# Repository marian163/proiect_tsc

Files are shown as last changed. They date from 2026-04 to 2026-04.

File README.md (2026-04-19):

# InkTime v6 — documentație hardware

## 1. Funcționalitatea hardware

InkTime v6 este un dispozitiv portabil cu ecran e-paper, construit în jurul microcontroller-ului **Nordic nRF52840** (Cortex-M4F @ 64 MHz, 1 MB Flash, 256 KB RAM, BLE 5, USB 2.0 full-speed, NFC-A). Cristalul principal de **32 MHz** (X1) alimentează CPU-ul și radio-ul, iar cristalul de **32.768 kHz** (X2) este folosit pentru RTC-ul low-power. Antena este un chip **2450AT18B100E** conectat la pinul ANT prin rețea de match în π (15 nH, 10 µH, 1 pF, 820 pF).

**Domeniul de alimentare.** Tensiunea intră prin conectorul **USB-C KH-TYPE-C-16P** (5 V VBUS), cu rezistențe CC de 5.1 kΩ care configurează placa ca UFP 500 mA și cu protecție ESD **USBLC6-2SC6Y** pe liniile D+/D−. VBUS ajunge la încărcătorul Li-Po **TI BQ25180** (I²C, adresă 0x6A), care gestionează o baterie Li-Po conectată prin **Molex 503480**. Ieșirea SYS a încărcătorului alimentează convertorul buck-boost **Richtek RT6160AWSC** (inductanța 0.47 µH + 10 µF/22 µF, feedback 3.3 kΩ) care produce șina stabilă **VREG = 3.3 V** indiferent de nivelul bateriei (3.0–4.2 V). Un **MAX17048** (I²C, 0x36) măsoară starea de încărcare prin ModelGauge fără shunt și generează ALERT la baterie scăzută.

**Periferice I²C.** Toate perifericele non-display partajează aceeași magistrală I²C cu nRF52840:

- **BMA421** (0x18) — accelerometru 3 axe Bosch, low-power (~14 µA @ 50 Hz), cu două linii de întrerupere (INT1, INT2) pentru detecție mișcare/tap/pas.
- **MAX17048** (0x36) — fuel gauge, cu pin ALERT open-drain.
- **DRV2605** (0x5A) — driver haptic cu bibliotecă internă de 123 efecte, cu pin EN dedicat pentru shutdown complet (~0.1 µA).
- **BQ25180** (0x6A) — încărcător, cu pin INT (PMIC_INT) pentru status de încărcare.

**Ecranul e-paper.** Conectorul FPC cu 24 de pini (J1) expune interfața SPI (MOSI, SCK, CS) plus semnale de control (DC, RST, BUSY) și alimentarea EPD_3V3. Tensiunile înalte necesare panelului (VGH ~+22 V, VGL ~−20 V) sunt generate local printr-un boost converter cu **inductanță 68 µH** + MOSFET N **SI1308** + diode Schottky **MBR0530** + condensatoare 1 µF / 50 V. Alimentarea logică a panelului este comutată de un PMOS **DMG2305UX-7**, permițând oprirea completă a ecranului între refresh-uri.

**Butoane și debug.** Trei butoane (SW_UP, SW_DN, SW_ENT) citite pe GPIO cu pull-up 10 kΩ. Header **TC2030-IDC** pentru SWD (SWDIO, SWDCLK, SWO, RESET).

**Consum estimat.** În sleep total ~30 µA (nRF52840 System OFF 1.5 µA + IMU low-power 4 µA + fuel gauge 23 µA + charger 1.5 µA, ecran complet off). Per refresh e-paper: ~25 mA timp de ~2 s. Cu o baterie de 150 mAh și 4 refresh-uri/zi + BLE advertising la 1 Hz, autonomia estimată este de ~100–130 zile.

---

## 2. Maparea pinilor nRF52840

Principii de alegere:

- pinii oscilatorilor (XL1/XL2, XC1/XC2), radio (ANT), USB (D+/D−) și NFC (NFC1/NFC2) sunt **fixați de chip** și nu pot fi folosiți altfel;
- liniile de întrerupere (INT1/INT2, ALERT, PMIC_INT, butoane) sunt plasate pe pini care permit wake-up din System OFF;
- magistralele seriale (I²C, SPI) sunt routabile liber pe orice GPIO — alegerile reflectă routing-ul fizic cel mai scurt pe PCB.

| Pin nRF52840 | Semnal | Funcție | Motiv alegere |
|---|---|---|---|
| P0.00 / XL1 | XL1 | Cristal 32.768 kHz | Pin dedicat oscilator LF |
| P0.01 / XL2 | XL2 | Cristal 32.768 kHz | Pin dedicat oscilator LF |
| XC1 / XC2 | HFCLK | Cristal 32 MHz | Pini dedicați oscilator HF |
| ANT | RF | Antenă 2.4 GHz | Pin dedicat radio |
| D+ / D− | USB data | USB-C (prin USBLC6) | Pini dedicați USB |
| VBUS | 5 V sense  | Detecție USB conectat | Pin dedicat USB |
| P0.04 | SDA | I²C data (shared) | GPIO central, routing scurt la toate perifericele |
| P1.09 | SCL | I²C clock (shared) | GPIO adiacent SDA |
| P0.13 | MOSI | SPI MOSI → e-paper | GPIO apropiat fizic de conector FPC |
| P0.14 | SCK | SPI clock → e-paper | GPIO adiacent MOSI |
| P0.26 | EPD_CS | SPI chip-select e-paper | GPIO simplu, aproape de FPC |
| P0.27 | EPD_DC | Data/Command e-paper | GPIO simplu, aproape de FPC |
| P1.01 | EPD_RST | Reset e-paper | GPIO (poate fi ținut low în sleep) |
| P1.02 | EPD_BUSY | Busy signal de la panel | GPIO intrare cu detecție de front |
| P1.03 | HAPTIC_EN  | Enable DRV2605 | GPIO simplu, low = shutdown |
| P1.04 | EPD_3V3_EN | Gate PMOS alimentare e-paper | GPIO simplu, controlează alimentarea panelului |
| P1.05 | IMU_INT1 | Întrerupere IMU (motion/activity) | Pin cu wake-up din System OFF |
| P1.06 | IMU_INT2 | Întrerupere IMU (tap/step) | Pin cu wake-up din System OFF |
| P1.07 | ALERT | Întrerupere fuel gauge | Pin cu wake-up (low-battery) |
| P1.08 | PMIC_INT | Întrerupere BQ25180 (charge status) | Pin cu wake-up |
| P0.22 | SW_UP | Buton sus | GPIO cu pull-up + wake-up |
| P0.23 | SW_DN | Buton jos | GPIO cu pull-up + wake-up |
| P0.24 | SW_ENT | Buton enter | GPIO cu pull-up + wake-up |
| SWDCLK | SWDCLK | Debug clock | Pin dedicat debug |
| SWDIO | SWDIO | Debug data | Pin dedicat debug |
| P0.18 / RESET | RESET | Reset hardware | Pin dedicat reset |
| P1.00 / SWO | SWO | Trace output (opțional) | Pin SWO dedicat |

---

## 3. Decizii de implementare

Ideal, schematicul ar fi trebuit împărțit pe două sheet-uri (MCU + alimentare separat de ecran + periferice), așa cum este modelul de referință. În practică, am desenat tot pe un singur sheet de la început și, până când mi-am dat seama că două ar fi fost mai lizibil, PCB-ul era deja rutat — orice restructurare a schematicului ar fi invalidat rutarea existentă. Am păstrat single-sheet-ul ca atare; este mai dens și mai greu de citit, dar funcțional.

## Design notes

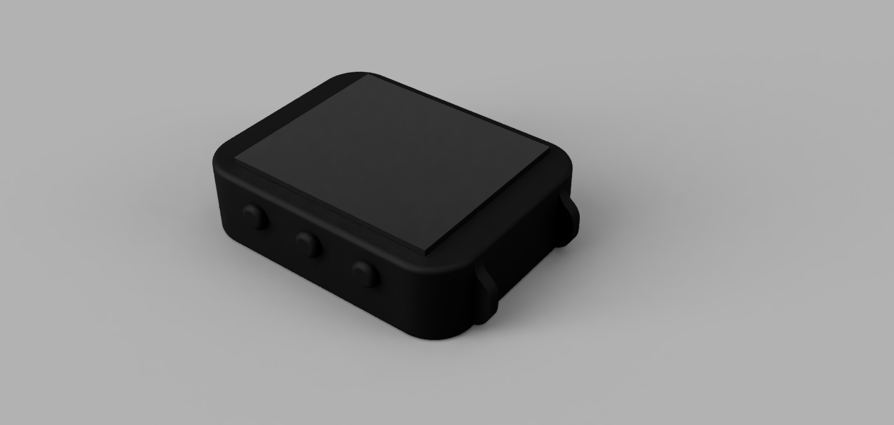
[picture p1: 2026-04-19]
Images/3d_Design_render.PNG

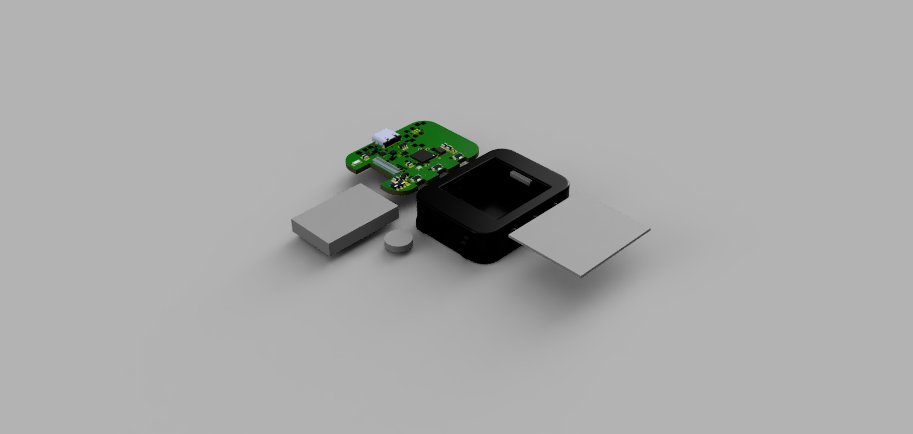
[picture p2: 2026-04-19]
Images/3D_Design_exploded_render.png

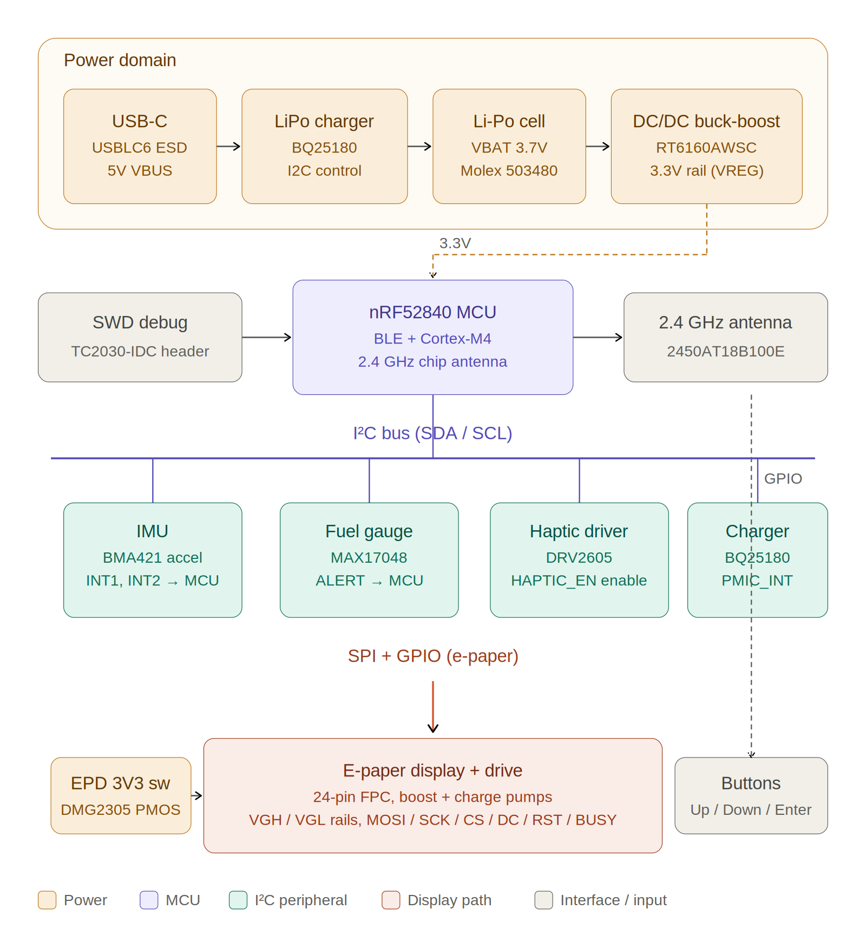
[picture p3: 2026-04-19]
Images/inktime_block_diagram.png

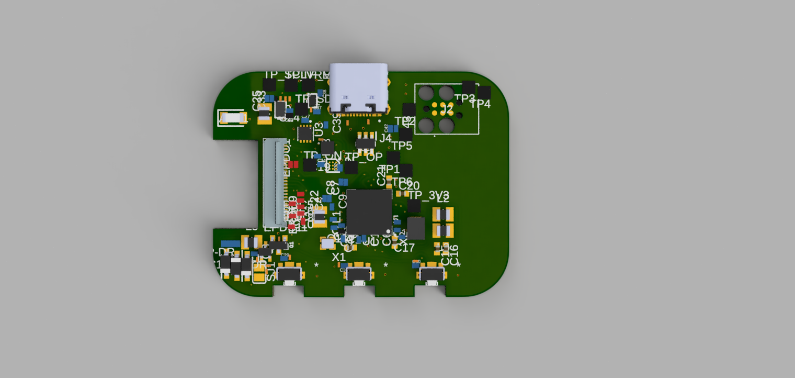
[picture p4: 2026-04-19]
Images/3D_PCB_render.PNG

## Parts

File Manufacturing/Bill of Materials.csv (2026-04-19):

Qty | Value | Device | Package | Parts | Description | ARROW_PART_NUMBER | ARROW_PRICE-STOCK | AVAILABILITY | CATEGORY | CHECK_PRICES | COPYRIGHT | DATASHEET | DESCRIPTION | DIGI-KEY_PART_NUMBER_1 | DIGI-KEY_PART_NUMBER_2 | DIGI-KEY_PART_NUMBER_3 | FREQUENCY | GPIO | HEIGHT | JLCPCB | L2 | L3 | MANUFACTURER | MANUFACTURER_NAME | MANUFACTURER_PART_NUMBER | MF | MOUSER_PART_NUMBER | MOUSER_PRICE-STOCK | MP | MPN | OPERATING_TEMPERATURE | PACKAGE | PACKAGE_SIZE | PACKAGE_TYPE | PART_STATUS | POPULARITY | PRICE | PROD_ID | PURCHASE-URL | R2 | R4 | R9 | ROHS | SERIES | SNAPEDA_LINK | SPICEMODEL | SPICEPREFIX | SUBCATEGORY | THERMALLOSS | TP_SIGNAL_NAME | TYPE | VALUE
1 | 0 | ERA-1AEB3401C_CPF0201D7K68C1 | ERA-1AEB3401C_0201 | R2 | 7.68k 0201 Thin Film Surface Mount Fixed Resistor +/-0.5% 0.031W CPF0201D7K68C1 |  |  |  |  |  |  |  |  |  |  |  |  |  |  |  |  |  |  |  |  |  |  |  |  |  |  |  |  |  |  |  |  |  |  |  | 0
2 | 0 | ERA-1AEB3401C_CPF0201D7K68C1 | ERA-1AEB3401C_0201 | R3, R4 | 7.68k 0201 Thin Film Surface Mount Fixed Resistor +/-0.5% 0.031W CPF0201D7K68C1 |  |  |  |  |  |  |  |  |  |  |  |  |  |  |  |  |  |  |  |  |  |  |  |  |  |  |  |  |  |  |  |  |  |  | 0
1 | 0 | ESP32_C6_LIBRARY_7_JUMPER_SJ | ESP32_C6_LIBRARY_7_JUMPER_SJ | SJ1 | SMD solder JUMPER |  |  |  |  |  |  |  |  |  |  |  |  |  |  |  |  |  |  |  |  |  |  |  |  |  |  |  |  |  |  | 3
3 | 0.1uF | GRM011R60J152KE01L_2_GRM011R60J152KE01L | GRM011R60J152KE01L_2_CAPC0201X13N | C23, C27, C42 | Check availability |  |  | In Stock |  | https://www.snapeda.com/parts/GRM011R60J152KE01L/Murata/view-part/?ref=eda |  |  | SMD Capacitor X5R(EIA) with Capacitance: 1500pF Tol. 10%. Rated Voltage: 6.3Vdc |  |  |  |  |  |  |  |  |  |  |  |  | Murata |  |  | GRM011R60J152KE01L |  |  | 0201 Murata |  |  |  |  | None |  |  |  |  |  |  |  | https://www.snapeda.com/parts/GRM011R60J152KE01L/Murata/view-part/?ref=snap
1 | 0.47 | ERA-1AEB3401C_CPF0201D7K68C1 | ERA-1AEB3401C_0201 | R1_EP_DR | 7.68k 0201 Thin Film Surface Mount Fixed Resistor +/-0.5% 0.031W CPF0201D7K68C1
1 | 01.uF | GRM011R60J152KE01L_2_GRM011R60J152KE01L | GRM011R60J152KE01L_2_CAPC0201X13N | C34 | Check availability |  |  | In Stock |  | https://www.snapeda.com/parts/GRM011R60J152KE01L/Murata/view-part/?ref=eda |  |  | SMD Capacitor X5R(EIA) with Capacitance: 1500pF Tol. 10%. Rated Voltage: 6.3Vdc |  |  |  |  |  |  |  |  |  |  |  |  | Murata |  |  | GRM011R60J152KE01L |  |  | 0201 Murata |  |  |  |  | None |  |  |  |  |  |  |  | https://www.snapeda.com/parts/GRM011R60J152KE01L/Murata/view-part/?ref=snap
1 | 1.0µF | ESP32_C6_LIBRARY_1_ESP32_WROVER_EAGLE-LTSPICE_CC0402 | ESP32_C6_LIBRARY_1_ESP32_WROVER_EAGLE-LTSPICE_C0402 | C15 | CAPACITOR, European symbol |  |  |  |  |  |  |  |  |  |  |  |  |  |  |  |  |  |  |  |  |  |  |  |  |  |  |  |  |  |  |  |  |  |  |  |  |  |  |  |  | NONE | C
5 | 100nF | NORDIC_NRF_3_CAPACITOR_0201_L | NORDIC_NRF_3_RESC0201_L | C5, C7, C8, C12, C19 | Generic chip capacitor
1 | 100pF | NORDIC_NRF_3_CAPACITOR_0201_L | NORDIC_NRF_3_RESC0201_L | C11 | Generic chip capacitor
5 | 10K | ERA-1AEB3401C_CPF0201D7K68C1 | ERA-1AEB3401C_0201 | R2_EP_DR, R5, R7, R8, R_PWR_EPD | 7.68k 0201 Thin Film Surface Mount Fixed Resistor +/-0.5% 0.031W CPF0201D7K68C1
1 | 10K | ERA-1AEB3401C_CPF0201D7K68C1 | ERA-1AEB3401C_0201 | R9 | 7.68k 0201 Thin Film Surface Mount Fixed Resistor +/-0.5% 0.031W CPF0201D7K68C1 |  |  |  |  |  |  |  |  |  |  |  |  |  |  |  |  |  |  |  |  |  |  |  |  |  |  |  |  |  |  |  |  |  |  |  |  | 10K
1 | 10nF | NORDIC_NRF_3_CAPACITOR_0201_L | NORDIC_NRF_3_RESC0201_L | C39 | Generic chip capacitor
2 | 10uF | NORDIC_NRF_3_CAPACITOR_0201_L | NORDIC_NRF_3_RESC0201_L | C1_EP_DR, C24 | Generic chip capacitor
1 | 10µH | MLP2016SR47MT0S1_FTC252012SR47MBCA | MLP2016SR47MT0S1_INDC2016X100N | L2 | SMD / SMT Inductors (Coils), L=0.47?H, L x W x T : |  |  |  |  |  |  |  | SMD / SMT Inductors (Coils) | L=0.47?H | L x W x T : |  |  |  |  |  | 1mm | https://jlcpcb.com/partdetail/6763488-FTC252012SR47MBCA/C5832368 | 10µH |  |  | TDK | FTC252012SR47MBCA
3 | 12pF | NORDIC_NRF_3_CAPACITOR_0201_L | NORDIC_NRF_3_RESC0201_L | C1, C17, C18 | Generic chip capacitor
1 | 15nH | MLP2016SR47MT0S1_FTC252012SR47MBCA | MLP2016SR47MT0S1_INDC2016X100N | L3 | SMD / SMT Inductors (Coils), L=0.47?H, L x W x T : |  |  |  |  |  |  |  | SMD / SMT Inductors (Coils) | L=0.47?H | L x W x T : |  |  |  |  |  | 1mm | https://jlcpcb.com/partdetail/6763488-FTC252012SR47MBCA/C5832368 |  | 15nH |  | TDK | FTC252012SR47MBCA
2 | 1pF | NORDIC_NRF_3_CAPACITOR_0201_L | NORDIC_NRF_3_RESC0201_L | C3, C4 | Generic chip capacitor
6 | 1uF | GRM011R60J152KE01L_2_GRM011R60J152KE01L | GRM011R60J152KE01L_2_CAPC0201X13N | C29, C30, C31, C32, C37, C38 | Check availability |  |  | In Stock |  | https://www.snapeda.com/parts/GRM011R60J152KE01L/Murata/view-part/?ref=eda |  |  | SMD Capacitor X5R(EIA) with Capacitance: 1500pF Tol. 10%. Rated Voltage: 6.3Vdc |  |  |  |  |  |  |  |  |  |  |  |  | Murata |  |  | GRM011R60J152KE01L |  |  | 0201 Murata |  |  |  |  | None |  |  |  |  |  |  |  | https://www.snapeda.com/parts/GRM011R60J152KE01L/Murata/view-part/?ref=snap
10 | 1uF/50V | NORDIC_NRF_3_CAPACITOR_0201_L | NORDIC_NRF_3_RESC0201_L | EPDC1, EPDC2, EPDC5, EPDC6, EPDC7, EPDC8, EPDC9, EPDC10, EPDC11, EPDC12 | Generic chip capacitor
1 | 2.2 | ERA-1AEB3401C_CPF0201D7K68C1 | ERA-1AEB3401C_0201 | R_TYPE_SEL | 7.68k 0201 Thin Film Surface Mount Fixed Resistor +/-0.5% 0.031W CPF0201D7K68C1
3 | 2025-10-22_07-23-44_LIBRARY_EVP-AKE31ASW_EVP-AKE31A_PAN | 2025-10-22_07-23-44_LIBRARY_EVP-AKE31ASW_EVP-AKE31A_PAN | 2025-10-22_07-23-44_LIBRARY_SW_EVP-AKE31A_PAN | SW_DN, SW_ENT, SW_UP |  |  |  |  |  |  | Copyright (C) 2025 Ultra Librarian. All rights reserved. |  |  | P123437TR-ND | P123437CT-ND | P123437DKR-ND |  |  |  |  |  |  |  | Panasonic | EVP-AKE31A
1 | 20V/4.2A/52mO/1.4W | ESP32_C6_LIBRARY_4_ESP32_WROVER_SPARKFUN-DISCRETESEMI_MOSFET_PCH-DMG2305UX-7 | ESP32_C6_LIBRARY_4_ESP32_C6_LIBRARY_4_ESP32_C6_LIBRARY_4_ESP32_C6_LIBRARY_4_ESP32_WROVER_SPARKFUN-DISCRETESEMI_SOT23-3 | Q1 | P-channel MOSFETs |  |  |  |  |  |  |  |  |  |  |  |  |  |  |  |  |  |  |  |  |  |  |  |  |  |  |  |  |  |  |  |  | TRAN-14388 |  |  |  |  |  |  |  |  |  |  |  |  |  | 20V/4.2A/52mO/1.4W
2 | 22nF | NORDIC_NRF_3_CAPACITOR_0201_L | NORDIC_NRF_3_RESC0201_L | C25, C33 | Generic chip capacitor
1 | 2450AT18B100E_2450AT18B100E | 2450AT18B100E_2450AT18B100E | 2450AT18B100E_ANTC3216X140N | ANT1 | Antennas 2.45GHz ANTENNA | 2450AT18B100E | https://www.arrow.com/en/products/2450at18b100e/johanson-dielectrics?utm_currency=USD&region=nac |  |  |  |  |  | Antennas 2.45GHz ANTENNA |  |  |  |  |  | 1.4mm |  |  |  |  | JOHANSON TECHNOLOGY | 2450AT18B100E |  | 609-2450AT18B100E | https://www.mouser.co.uk/ProductDetail/Johanson-Technology/2450AT18B100E?qs=yCnrNFeXz%252Bh5MFsFIXGZGA%3D%3D
1 | 32.768kH | NORDIC_NRF_1_XTAL_32KHZ | NORDIC_NRF_1_XTAL_3215_N | X2
1 | 32MHz | NORDIC_NRF_XTAL_32MHZ | NORDIC_NRF_BT-XTAL_2016_N | X1
1 | 4.7nF | NORDIC_NRF_3_CAPACITOR_0201_L | NORDIC_NRF_3_RESC0201_L | C43 | Generic chip capacitor
1 | 4.7uF | ESP32_C6_LIBRARY_1_ESP32_WROVER_EAGLE-LTSPICE_CC0402 | ESP32_C6_LIBRARY_1_ESP32_WROVER_EAGLE-LTSPICE_C0402 | C2-EP-DR | CAPACITOR, European symbol |  |  |  |  |  |  |  |  |  |  |  |  |  |  |  |  |  |  |  |  |  |  |  |  |  |  |  |  |  |  |  |  |  |  |  |  |  |  |  |  | NONE | C
4 | 4.7µF | ESP32_C6_LIBRARY_1_ESP32_WROVER_EAGLE-LTSPICE_CC0402 | ESP32_C6_LIBRARY_1_ESP32_WROVER_EAGLE-LTSPICE_C0402 | C6, C14, C20, C21 | CAPACITOR, European symbol |  |  |  |  |  |  |  |  |  |  |  |  |  |  |  |  |  |  |  |  |  |  |  |  |  |  |  |  |  |  |  |  |  |  |  |  |  |  |  |  | NONE | C
1 | 47nF | ESP32_C6_LIBRARY_1_ESP32_WROVER_EAGLE-LTSPICE_CC0402 | ESP32_C6_LIBRARY_1_ESP32_WROVER_EAGLE-LTSPICE_C0402 | C16 | CAPACITOR, European symbol |  |  |  |  |  |  |  |  |  |  |  |  |  |  |  |  |  |  |  |  |  |  |  |  |  |  |  |  |  |  |  |  |  |  |  |  |  |  |  |  | NONE | C
1 | 503480-2400_503480-2400 | 503480-2400_503480-2400 | 503480-2400_5034802400 | J1 | FFC & FPC Connectors 0.5mm FPC RA SMT Dual Contact 24Ckt |  |  |  |  |  |  |  | FFC & FPC Connectors 0.5mm FPC RA SMT Dual Contact 24Ckt |  |  |  |  |  | 1.87mm |  |  |  |  | Molex | 503480-2400 |  | 538-503480-2400 | https://www.mouser.co.uk/ProductDetail/Molex/503480-2400?qs=OAhjpuo3Vu7efIoxFh9AOw%3D%3D
2 | 5K1 | ERA-1AEB3401C_CPF0201D7K68C1 | ERA-1AEB3401C_0201 | R1_USB, R2_USB | 7.68k 0201 Thin Film Surface Mount Fixed Resistor +/-0.5% 0.031W CPF0201D7K68C1
1 | 68uH | MLP2016SR47MT0S1_FTC252012SR47MBCA | MLP2016SR47MT0S1_INDC2016X100N | L5 | SMD / SMT Inductors (Coils), L=0.47?H, L x W x T : |  |  |  |  |  |  |  | SMD / SMT Inductors (Coils) | L=0.47?H | L x W x T : |  |  |  |  |  | 1mm | https://jlcpcb.com/partdetail/6763488-FTC252012SR47MBCA/C5832368 |  |  |  | TDK | FTC252012SR47MBCA
1 | 820pF | NORDIC_NRF_3_CAPACITOR_0201_L | NORDIC_NRF_3_RESC0201_L | C9 | Generic chip capacitor
1 | BMA423_BMA423 | BMA423_BMA423 | BMA423_BMA423 | IC3 | Accelerometers Triaxial low-g 12bit Acceleration Sensor | BMA423 | https://www.arrow.com/en/products/bma423/bosch |  |  |  |  |  | Accelerometers Triaxial low-g 12bit Acceleration Sensor |  |  |  |  |  | 1mm |  |  |  |  | BOSCH | BMA423 |  | 262-BMA423 | https://www.mouser.co.uk/ProductDetail/Bosch-Sensortec/BMA423?qs=HXFqYaX1Q2xC%252BSgeGoX3mg%3D%3D
1 | BQ25180YBGR_BQ25180YBGR | BQ25180YBGR_BQ25180YBGR | BQ25180YBGR_BGA8C40P2X4_100X155X50 | IC1 | Charger IC Lithium Ion/Polymer, Lithium Iron Phosphate 8-DSBGA (1.6x1.1) | BQ25180YBGR | https://www.arrow.com/en/products/bq25180ybgr/texas-instruments?utm_currency=USD&region=nac |  |  |  |  |  | Charger IC Lithium Ion/Polymer | Lithium Iron Phosphate 8-DSBGA (1.6x1.1) |  |  |  |  |  | 0.5mm |  |  |  |  | Texas Instruments | BQ25180YBGR |  | 595-BQ25180YBGR | https://www.mouser.co.uk/ProductDetail/Texas-Instruments/BQ25180YBGR?qs=doiCPypUmgEWjAK%252BJAX6Tw%3D%3D
1 | DRV2605YZFR_DRV2605YZFR | DRV2605YZFR_DRV2605YZFR | DRV2605YZFR_BGA9C50P3X3_144X144X62 | IC2 | Haptic Driver for ERM/LRA with Built-In Library and Smart Loop Architecture | DRV2605YZFR | https://www.arrow.com/en/products/drv2605yzfr/texas-instruments?region=nac |  |  |  |  |  | Haptic Driver for ERM/LRA with Built-In Library and Smart Loop Architecture |  |  |  |  |  | 0.625mm |  |  |  |  | Texas Instruments | DRV2605YZFR
2 | ERA-1AEB3401C_CPF0201D7K68C1 | ERA-1AEB3401C_CPF0201D7K68C1 | ERA-1AEB3401C_0201 | R17, R18 | 7.68k 0201 Thin Film Surface Mount Fixed Resistor +/-0.5% 0.031W CPF0201D7K68C1
1 | ESP32_C6_LIBRARY_3_USBLC6-2SC6Y | ESP32_C6_LIBRARY_3_USBLC6-2SC6Y | ESP32_C6_LIBRARY_3_SOT95P280X145-6N | D3 | Low Cap. ESD Protection Auto SOT-23-6 STMicroelectronics USBLC6-2SC6Y, Dual Uni-Directional TVS Diode Array, 6-Pin SOT-23 |  |  | In Stock |  | https://www.snapeda.com/parts/USBLC6-2SC6Y/STMicroelectronics/view-part/?ref=eda |  |  | 17V Clamp 5A (8/20µs) Ipp Tvs Diode Surface Mount SOT-23-6 |  |  |  |  |  |  |  |  |  |  |  |  | STMicroelectronics |  |  | USBLC6-2SC6Y |  |  | SOT-23-6 STMicroelectronics |  |  |  |  | None |  |  |  |  |  |  |  | https://www.snapeda.com/parts/USBLC6-2SC6Y/STMicroelectronics/view-part/?ref=snap
3 | ESP32_C6_LIBRARY_5_MBR0530 | ESP32_C6_LIBRARY_5_MBR0530 | ESP32_C6_LIBRARY_5_SOD3716X135N | D2, D4, D5 | ON SEMICONDUCTOR - MBR0530 - DIODE, SCHOTTKY, 0.5A, 30V, SOD-123 |  |  | In Stock |  | https://www.snapeda.com/parts/MBR0530/Onsemi/view-part/?ref=eda |  |  | Diode Schottky 30 V 500mA Surface Mount SOD-123 |  |  |  |  |  |  |  |  |  |  |  |  | ON Semiconductor |  |  | MBR0530 |  |  | SOD-123-2 ON Semiconductor |  |  |  |  | None |  | https://www.snapeda.com/api/url_track_click_mouser/?unipart_id=179458&manufacturer=ON Semiconductor&part_name=MBR0530&search_term=None |  |  |  |  |  | https://www.snapeda.com/parts/MBR0530/Onsemi/view-part/?ref=snap
1 | ESP32_C6_LIBRARY_6_SI1308EDL-T1-GE3 | ESP32_C6_LIBRARY_6_SI1308EDL-T1-GE3 | ESP32_C6_LIBRARY_6_SOT65P210X110-3N | Q3 | MOSFET N-Ch 30V 1.5A TrenchFET SC70 Vishay Si1308EDL-T1-GE3 N-channel MOSFET Transistor, 1.5 A, 30 V, 3-Pin SC-70 |  |  | In Stock |  | https://www.snapeda.com/parts/SI1308EDL-T1-GE3/Vishay+Siliconix/view-part/?ref=eda |  |  | Si1308EDL-T1-GE3 N-channel MOSFET Transistor | 1.5 A | 30 V | 3-Pin SC-70 | Siliconix / Vishay SI1308EDL-T1-GE3 |  |  |  |  |  |  |  |  |  |  |  |  | Vishay Siliconix |  |  | SI1308EDL-T1-GE3 |  |  | SOT-323 Vishay Semiconductor |  |  |  |  | None |  | https://www.snapeda.com/api/url_track_click_mouser/?unipart_id=274603&manufacturer=Vishay Siliconix&part_name=SI1308EDL-T1-GE3&search_term=None |  |  |  |  |  | https://www.snapeda.com/parts/SI1308EDL-T1-GE3/Vishay+Siliconix/view-part/?ref=snap
1 | ESP32_C6_LIBRARY_MAX17048G+T10 | ESP32_C6_LIBRARY_MAX17048G+T10 | ESP32_C6_LIBRARY_SON50P200X200X80-9N | U3 | Check availability |  |  | In Stock |  | https://www.snapeda.com/parts/MAX17048G+T10/Analog+Devices/view-part/?ref=eda |  |  | 3µA 1-Cell/2-Cell Fuel Gauge with ModelGauge |  |  |  |  |  |  |  |  |  |  |  |  | Analog Devices |  |  | MAX17048G+T10 |  |  | TDFN-8 Maxim |  |  |  |  | None |  | https://www.snapeda.com/api/url_track_click_mouser/?unipart_id=329239&manufacturer=Analog Devices&part_name=MAX17048G+T10&search_term=None |  |  |  |  |  | https://www.snapeda.com/parts/MAX17048G+T10/Analog+Devices/view-part/?ref=snap
13 | HECTOR_WATCH_1_TPTP20R | HECTOR_WATCH_1_TPTP20R | HECTOR_WATCH_1_TP20R | TP1, TP2, TP3, TP4, TP5, TP6, TP_3V3, TP_ON, TP_OP, TP_SCL, TP_SDA, TP_VBAT, TP_VREG | Test pad |  |  |  |  |  |  |  |  |  |  |  |  |  |  |  |  |  |  |  |  |  |  |  |  |  |  |  |  |  |  | 2
1 | KH-TYPE-C-16P_KH-TYPE-C-16P | KH-TYPE-C-16P_KH-TYPE-C-16P | KH-TYPE-C-16P_KINGHELM_KH-TYPE-C-16P | J4 | Check availability |  |  | Not in stock |  | https://www.snapeda.com/parts/KH-TYPE-C-16P/Kinghelm/view-part/?ref=eda |  |  |  |  |  |  |  |  |  |  |  |  |  |  |  | kinghelm |  |  | KH-TYPE-C-16P |  |  | None |  |  |  |  | None |  |  |  |  |  |  |  | https://www.snapeda.com/parts/KH-TYPE-C-16P/Kinghelm/view-part/?ref=snap
2 | MLP2016SR47MT0S1_FTC252012SR47MBCA | MLP2016SR47MT0S1_FTC252012SR47MBCA | MLP2016SR47MT0S1_INDC2016X100N | L1, L7 | SMD / SMT Inductors (Coils), L=0.47?H, L x W x T : |  |  |  |  |  |  |  | SMD / SMT Inductors (Coils) | L=0.47?H | L x W x T : |  |  |  |  |  | 1mm | https://jlcpcb.com/partdetail/6763488-FTC252012SR47MBCA/C5832368 |  |  |  | TDK | FTC252012SR47MBCA
4 | N.C. | NORDIC_NRF_3_CAPACITOR_0201_L | NORDIC_NRF_3_RESC0201_L | C2, C10, C13, C22 | Generic chip capacitor
1 | NRF52840-QIAA-R | NRF52840-QIAA-R | NRF52840-QIAA | U1 | Bluetooth®5 IEEE 802.15.4-2006 2.4 GHz transceiver - SoC |  |  |  | RF and Wireless ICs |  |  | https://mm.digikey.com/Volume0/opasdata/d220001/medias/docus/6470/NRF52840-QIAA-R.pdf | IC RF TxRx + MCU 802.15.4 Bluetooth Bluetooth v5.0 2.4 GHz 73-VFQFN Dual Rows Exposed Pad |  |  |  | 2.4 GHz | 48 |  |  |  |  | Nordic Semiconductor ASA |  |  |  |  |  |  | NRF52840-QIAA-R | -40°C ~ 85°C |  | 73-VFQFN | Surface Mount | Active |  |  |  |  |  |  |  | Compliant | NRF52840 |  |  |  | Bluetooth |  |  | TxRx + MCU
1 | RT6160AWSC_RT6160AWSC | RT6160AWSC_RT6160AWSC | RT6160AWSC_BGA15C40P3X5_140X230X60 | IC9 | Buck-Boost Regulator Positive Output Step-Up/Step-Down I2C DC-DC Controller IC 15-WL-CSP (BSC) (1.4x2.3) |  |  |  |  |  |  |  | Buck-Boost Regulator Positive Output Step-Up/Step-Down I2C DC-DC Controller IC 15-WL-CSP (BSC) (1.4x2.3) |  |  |  |  |  | 0.6mm |  |  |  |  | RICHTEK | RT6160AWSC |  | 835-RT6160AWSC | https://www.mouser.co.uk/ProductDetail/Richtek/RT6160AWSC?qs=amGC7iS6iy%2FLd9PSoixZXQ%3D%3D
1 | TC2030-IDC_TC2030-IDC | TC2030-IDC_TC2030-IDC | TC2030-IDC_TC2030IDC | J2 | CABLE ADAPTER 6 POS |  |  |  |  |  |  |  | CABLE ADAPTER 6 POS |  |  |  |  |  | 19mm |  |  |  |  | Tag Connect | TC2030-IDC

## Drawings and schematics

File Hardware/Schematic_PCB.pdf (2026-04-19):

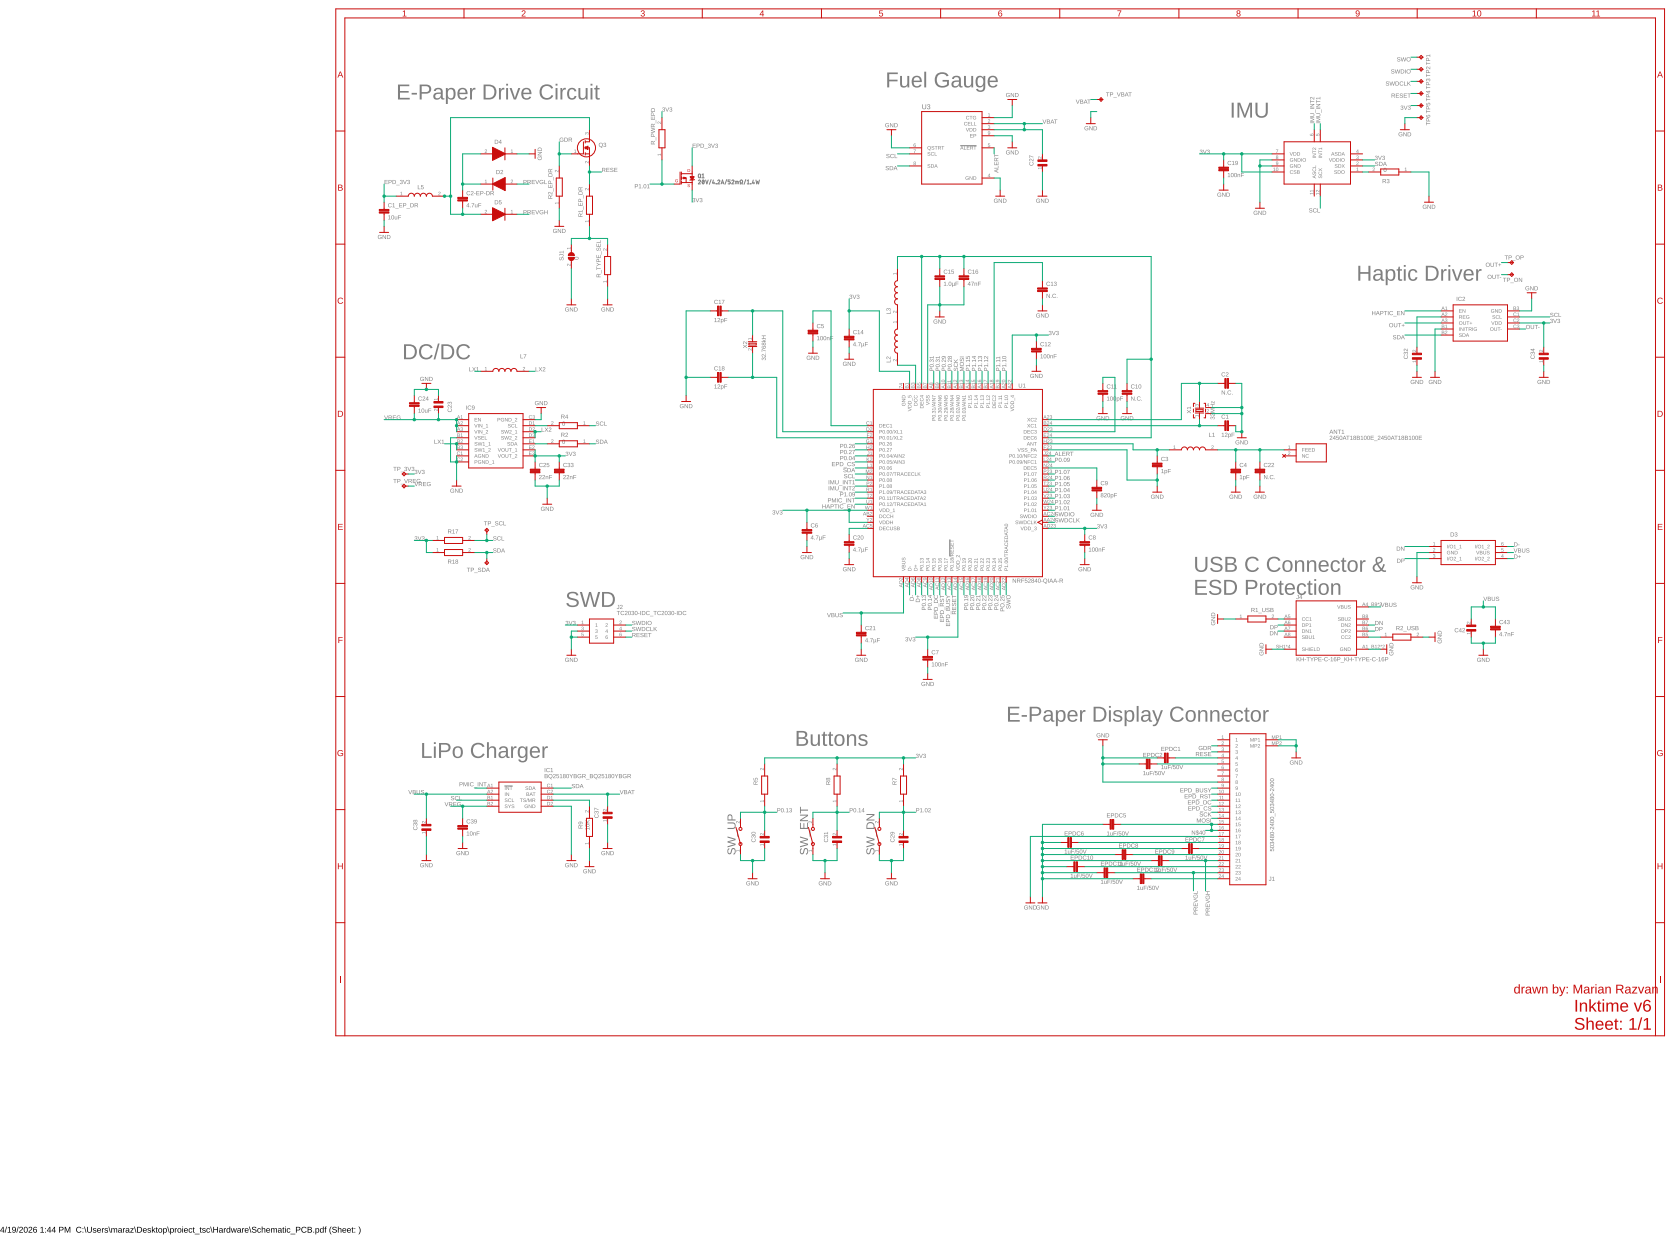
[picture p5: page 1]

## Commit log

2026-04-10 removed 3d pcb from root
2026-04-10 gerber add
    [copper_bottom_l4.gbr, copper_inner_l2.gbr, copper_inner_l3.gbr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]
